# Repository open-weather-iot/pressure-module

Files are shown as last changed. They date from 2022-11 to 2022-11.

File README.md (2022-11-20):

# MÓDULO DE PRESSÃO ATMOSFÉRICA

O módulo de pressão atmosférica faz parte do projeto de estação meteorológica no âmbito da disciplina de Laboratorio Experimental de Campus Inteligente (IE321K - 2S2022).

O sensor utilizado é o [BME680](https://br.mouser.com/datasheet/2/783/BST_BME680_DS001-1509608.pdf) que além da pressão atmosférica, realiza medição de outras grandezas como temperatura, umidade relativa do ar, altitude e qualidade do ar.

## Protótipo

Foi realizado um protótipo inicial para avaliar as medições do sensor e dinâmica de funcionamento do software.

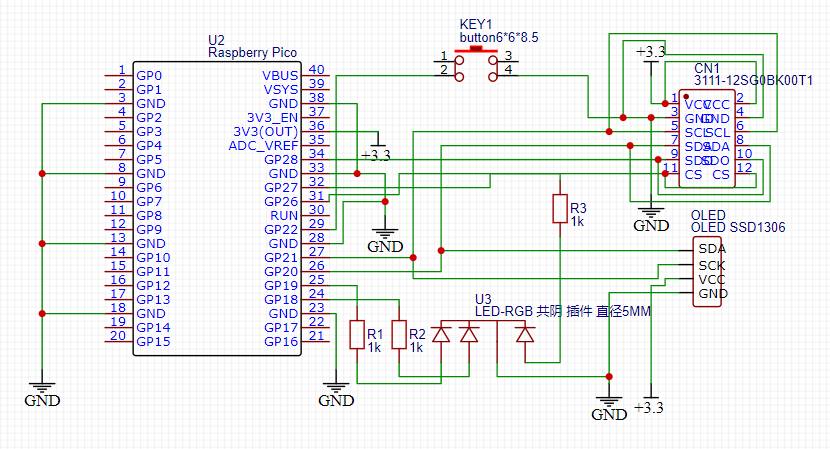
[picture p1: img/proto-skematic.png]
Skematics


Para o circuito foram utilizados os seguintes componentes:

* RaspberryPi Pico 
* Módulo sensor BME680
* 1 Tela (_Display_ OLED 128x32)
* 1 LED RGB
* 1 Botão (_Push button_)

**Funcionamento:** O LED RGB informa a cor verde indicando funcionamento normal do sistema. A cada leitura do sensor e pressionamento do botão, o LED pisca.
O botão serve para alternar a exibição na tela das 5 grandezas exibidas pelo sensor, sendo que inicialmente é exibido primeiro o valor de pressão atmosférica.
As medições ocorrem a cada 10 segundos. Caso ocorra algum erro com a leitura I2C do sensor, o LED vai alternar para vermelho, piscando a cada 10 segundos também. Ao restabelecer a conexão I2C, retorna ao estado normal (verde). O fluxo de tratamento do display ficou isolado, portanto em caso de falha, os dados continuam podendo ser exibidos e alternados no display, porém vai exibir o valor da última medição obtida, até que se reestabeleça o sensor novamente.

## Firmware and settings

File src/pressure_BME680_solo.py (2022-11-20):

"""
Código para validação do funcionamento do BME680 + OLED

Botão de chaveamento de informações do sensor

    O botão serve para chavear no display as diferentes grandezas capturadas pelo sensor:

        * Pressão Atmosférica
        * Temperatura
        * Umidade
        * Qualidade do ar
        * Altitude

LED RGB de indicação de funcionamento ou falha

    * LED em verde indica que o circuito está funcional
    * LED pisca em verde quando executa leitura do sensor
    * LED pisca em verde quando pressiona o botão
    * LED pisca em vermelho quando há falha de leitura do sensor
"""
import sys

from machine import Pin, I2C
from bme680 import BME680_I2C
from time import ticks_ms, sleep_ms
import ssd1306

# Definição dos valores de on/off para LED RGB:
# Anodo comum  => on=0, off=1
# Catodo comum => on=1, off=0
LED_ON = 1
LED_OFF = 0

NORMAL_STATE_FREQ_MS = 10000
ERROR_STATE_FREQ_MS = 5000
DEBOUNCE_TIME_MS = 107

SENSOR_ADDR = 119
DISPLAY_ADDR = 60
IN_ERROR_STATE = False

# Configuração I2C da Pico
# Usaremos I2C 0, GPIO 20 e 21 --> SDA e SCL
i2c = I2C(0, scl=Pin(21), sda=Pin(20))
bme = BME680_I2C(i2c=i2c)
display = ssd1306.SSD1306_I2C(128, 32, i2c)

# Configuração das GPIOs para Botão e Leds
button = Pin(22, Pin.IN, Pin.PULL_UP)
led_R = Pin(27, Pin.OUT)
led_G = Pin(18, Pin.OUT)
led_B = Pin(19, Pin.OUT)

# Definindo estado inicial do LED RGB
led_R.value(LED_OFF)
led_G.value(LED_ON)
led_B.value(LED_OFF)

# Variáveis
state = -1
relogio_bme = ticks_ms()
button_time = ticks_ms()
temp = ''
hum = ''
pres = ''
ar = ''
alt = ''

def blink_alert():
    toggle_RGB(LED_OFF)
    sleep_ms(400)
    led_R.toggle()

def blink_display_disconnected():
    toggle_RGB(LED_OFF)
    sleep_ms(400)
    led_B.toggle()

def blink_functional():
    toggle_RGB(LED_OFF)
    sleep_ms(200)
    led_G.toggle()

def toggle_RGB(led_value):
    led_R.value(led_value)
    led_G.value(led_value)
    led_B.value(led_value)

def check_device_alert(device_id):
    if device_id == SENSOR_ADDR:
        blink_alert()
    elif device_id == DISPLAY_ADDR:
        blink_display_disconnected()
    else:
        toggle_RGB(LED_OFF)

while True:    
    # Leitura do botão com debounced
    if(button.value() == 0):
        # Debounced
        if(button.value() == 0) and (ticks_ms() - button_time > DEBOUNCE_TIME_MS):
            button_time = ticks_ms()
            state = state + 1
            if state > 4:
                state = 0
            if not IN_ERROR_STATE:
                blink_functional()
            print(f'button state: {state}')

    if(state == 0):
        display.fill(0)
        display.text('Pressao: ', 0, 0)
        display.text(pres, 0, 24)
#         display.show()
#             print(f'Pressao: {f_pressure}')
    elif(state == 1):
        display.fill(0)
        display.text('Temperatura: ', 0, 0)
        display.text(temp, 0, 24)
#             print(f'Temperatura: {f_temperature}')
    elif(state == 2):
        display.fill(0)
        display.text('Umidade Relativa: ', 0, 0)
        display.text(hum, 0, 24)
#             print(f'Umidade Relativa: {f_humidity}')
    elif(state == 3):
        display.fill(0)
        display.text('Altitude: ', 0, 0)
        display.text(alt, 0, 24)
#             print(f'Altitude: {alt}')
    elif(state == 4):
        display.fill(0)
        display.text('Qualidade do Ar: ', 0, 0)
        display.text(ar, 0, 24)
#             print(f'Qualidade do Ar: {ar}')
    try:
        display.show()
        # Obtenção dos parâmetros a cada 10 [s]
        if((ticks_ms() - relogio_bme) > NORMAL_STATE_FREQ_MS):
#             print('error state: ' + str(IN_ERROR_STATE))
            print('reading data')
            f_temperature = "%0.1f C" % bme.temperature
            f_humidity = "%0.1f %%" % bme.humidity
            f_pressure = "%0.3f hPa" % bme.pressure
            temp = str(round(bme.temperature, 2)) + ' C'
            print(f'\nTemperatura: {f_temperature}')
            hum = str(round(bme.humidity, 2)) + ' %'
            print(f'Umidade: {f_humidity}')
            pres = str(round(bme.pressure, 2)) + ' hPa'
            print(f'Pressão: {f_pressure}\n')
            ar = str(round(bme.gas/1000, 2)) + ' KOhms'
            alt = str(round(bme.altitude, 2)) + ' m'
            
            relogio_bme = ticks_ms()

            IN_ERROR_STATE = False
            blink_functional()
#             print('\n----END OF FLOW----\n')
    except OSError as ose:
#         print('\n----ERROR INIT----\n')        
        IN_ERROR_STATE = True
        
        print(f'\nOSError: {ose}')
        devices = i2c.scan()
        print(f'Devices found: {devices}')
        if (len(devices) == 0):
            blink_alert()
        elif SENSOR_ADDR not in devices:
            print('sensor disconnected')
            check_device_alert(SENSOR_ADDR)
        elif DISPLAY_ADDR not in devices:
            print('display disconnected')
            check_device_alert(DISPLAY_ADDR)
                
        relogio_bme = ticks_ms()        
#         print('error state: ' + str(IN_ERROR_STATE))
#         print('\n----ERROR END----\n')
    except KeyboardInterrupt as k:
        sys.exit()
    except BaseException as e:
        print(type(e))
        print(f'Unexpected {e}')

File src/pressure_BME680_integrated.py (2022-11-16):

from machine import Pin, I2C
from bme680 import BME680_I2C

class Pressure_BME680:

    # deve receber os parâmetros nomeados necessários e o barramento utilizado (seja SPI, Serial ou I2C)
    def __init__(self, *, i2c_id, clk_pin, sda_pin):
        self.i2c = I2C(i2c_id, scl=Pin(clk_pin), sda=Pin(sda_pin))
        self.bme = BME680_I2C(i2c=self.i2c)
        # self.led_R = Pin(r_pin, Pin.OUT)
        # self.led_G = Pin(g_pin, Pin.OUT)
        # self.led_B = Pin(b_pin, Pin.OUT)


    # método **OPCIONAL** da classe que realiza a inicialização do sensor
    def setup(self):
        pass

    # método **OBRIGATÓRIO** da classe que realiza leituras do sensor
    def read(self, state):
        if(state == 0):
            f_pressure = "%0.3f hPa" % self.bme.pressure
            pres = round(self.bme.pressure, 2)
            print(f'Pressao: {f_pressure}\n')
            return { 'raw': self.bme.pressure, 'value': pres, 'unit': 'hPa' }
        elif(state == 1):
            f_temperature = "%0.1f C" % self.bme.temperature
            temp = round(self.bme.temperature, 2)
            print(f'\nTemperatura: {f_temperature}')
            return { 'raw': self.bme.temperature, 'value': temp, 'unit': 'C' }
        elif(state == 2):
            f_humidity = "%0.1f %%" % self.bme.humidity
            hum = round(self.bme.humidity, 2)
            print(f'Umidade: {f_humidity}')
            return { 'raw': self.bme.humidity, 'value': hum, 'unit': '%' }
        elif(state == 3):
            alt = round(self.bme.altitude, 2)
            print(f'Altitude: {alt}')
            return { 'raw': self.bme.altitude, 'value': alt, 'unit': 'm' }
        elif(state == 4):
            ar = round(self.bme.gas/1000, 2)
            print(f'Qualidade do Ar: {ar}')
            return { 'raw': self.bme.gas, 'value': ar, 'unit': 'KOhms' }
        # raw: os valores puros que foram lidos do sensor que se está trabalhando
        # value: representa o valor após conversão de unidades para ser apresentado diretamente ao usuário final
        # unit: unidade de medida
        return { 'raw': {}, 'value': 0.0, 'unit': '' }

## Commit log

2022-11-12 Update README
    Add basic information about the prototype and its functionality
2022-11-14 add pressure sensor first draft code
2022-11-16 add circuit libs
2022-11-16 sync pin values with PCB + remove sleep
2022-11-16 Update pressure_BME680_solo.py
    Código base elaborado por Manassés, em que fiz algumas modificações. Vale ressaltar que o código ainda utiliza sleep_ms(), porém não vejo problema de estar aqui visto que para o código elaborado para ser integrado não levará as funcionalidades que utilizam os sleep_ms().
    [pressure_BME680_solo.py]
2022-11-16 Add files via upload
    Layout da PCB atualizada. O primeiro modelo, que foi impresso, tinha as pinagens do OLED invertidos e o conector IDC era de 2mm o espaçamento. Para esse modelo fizemos a alteração do OLED e mantivemo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
    [PCB_BME680_circuit_ajustes_2022-11-16.pcbdoc]
2022-11-16 Add files via upload
    Esquemático da PCB do módulo do sensor BME680. A mesma segue as ligações da PCB implementada e testada em sala. Todo a elaboração foi feita no EasyEDA.
    [Sheet_1_2022-11-16.schdoc]
2022-11-16 Add files via upload
    Gerber utilizado para impressão da PCB produzida e testada no desenvolvimento.
2022-11-20 * isolate display functionalities from sensor read * refactor error handling: sensor OK, display need more testing * minor changes like new constants creation for some values
    [pressure_BME680_solo.py]
